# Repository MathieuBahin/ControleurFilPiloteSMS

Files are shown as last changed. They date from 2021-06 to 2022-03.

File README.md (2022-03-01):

# Controleur radiateur avec fil pilote par SMS

Bonjour à tous je vous propose aujourd'hui un projet pour contrôler un radiateur par SMS. Le radiateur doit posséder l'option "Fil pilote".

Mon besoin est de pouvoir piloter la mise en marche d'un radiateur situé dans une résidence secondaire à distance. L'idée est de pouvoir envoyer un ordre à une unité réceptrice qui va allumer le radiateur et me permettre d'arriver 1/2 jours plus tard avec une température correcte dans la résidence.

Des produits similaires existent mais la plupart proposent une communication par Internet, non compatible avec la configuration de la résidence secondaire.

Attention vous allez manipuler des courants mortels je vous conseille une grande vigilance lors des manipulations.

## Electronique

### La communication par fil pilote
On retrouve ci-dessous les commandes pour piloter le radiateur :

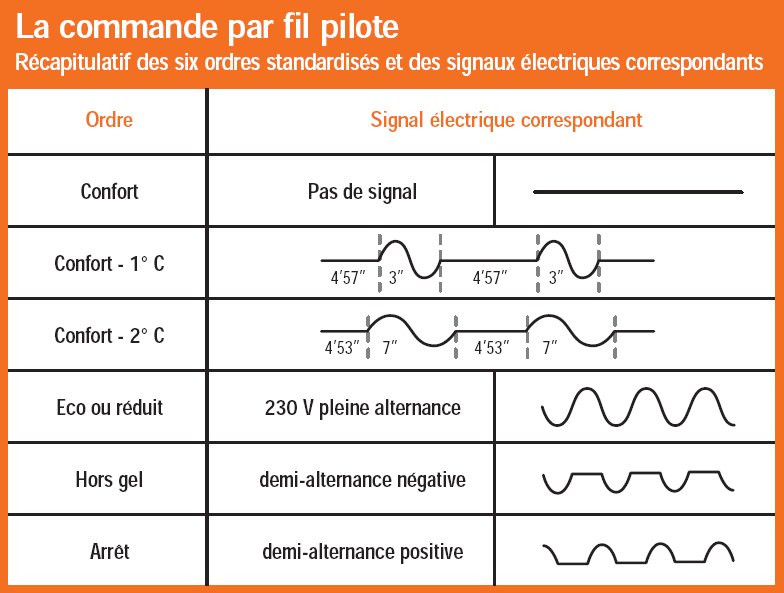
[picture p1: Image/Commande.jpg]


[Source](https://www.planete-domotique.com/blog/2012/01/05/piloter-un-radiateur-grace-a-son-fil-pilote/)

Le radiateur est donc piloté grâce à la sinusoïde 230V.

Pour créer les demi-alternances positives et négatives on utilise les optocoupleurs et les diodes.

En effet une diode dans le sens passant du 230V créer une demi-alternance positive et une diode dans le sens non passant crée une demi-alternance négative. Les optocoupleurs permettent de choisir si le chemin positif, négatif ou les deux sont utilisés.

### Composants utilisés
Pour le projet voici les composants utilisés : 

| Nom |  Coût |
| --- |:-----:|
| Arduino Nano x1 | 2€  |
| [SIM800L](https://www.amazon.fr/Sim800l-Quadribande-Embarqu%C3%A9e-Antenne-Arduino/dp/B01FQPLG9W) x1 | 6€ |
| [DS18B20](https://www.amazon.fr/ANGEEK-capteurs-temp%C3%A9rature-num%C3%A9riques-TO92-55%C2%B0C/dp/B07VB25GS5/) x1 |  8€ pour 5 |
| [IRM-10-5](https://fr.rs-online.com/web/p/alimentations-a-decoupage/1358929/) x1 |  10€ |
| [ZFKDS gauche](https://fr.rs-online.com/web/p/borniers-pour-circuits-imprimes/8045105/)  x1 | 0.50€ |
| [ZFKDS droit](https://fr.rs-online.com/web/p/borniers-pour-circuits-imprimes/8045102/) x1  | 16.70€ pour 50 |
| [MOC3043M](https://fr.rs-online.com/web/p/optocoupleurs/1611159) x2 | 7.76€ pour 10 |
| Résistance 4.7k | |
| Résistance 1.8k | |
| Résistance 1k | |
| Résistance 680 | |
| Diode 1N4007 x3 | |
| Condensateur 470µF [Farnell](https://fr.farnell.com/panasonic-electronic-components/eeufr0j471/condensateur-470-f-6-3v-20/dp/2805615) | |

Le capteur de température et la résistance R9 associée sont optionnels.
Les connecteurs ZFKDS peuvent être remplacés par des borniers etc.
Le condensateur n'est pas optionnel.
Le microcontrôleur Arduino est remplaçable par d'autres (par exemple un PIC8F ou autres) mais le code ne sera pas portable sur les autres plateformes telles quelles.

## Projet KiCad
Les fichiers KiCad sont situés dans le dossier KiCad. Les PCB sont gravés chez [JLCPCB](https://jlcpcb.com/).

Attention pour le module SIM800L a la tension d'alimentation qui est spéciale. J'utilise la tension de chute de la diode pour l'alimenter selon la datasheet. Un pont diviseur est également nécessaire pour la communication UART (5V → 3.3V).

Une fois le PCB reçu je vous conseille de souder le transformateur en dernier.

Si vous souhaitez faire une vérification sur le 230V à la sortie du fil pilote noté que votre multimètre ne vous indiquera pas 115V et si vous souhaitez vérifier avec un oscilloscope faite attention à utiliser une sonde différentielle !

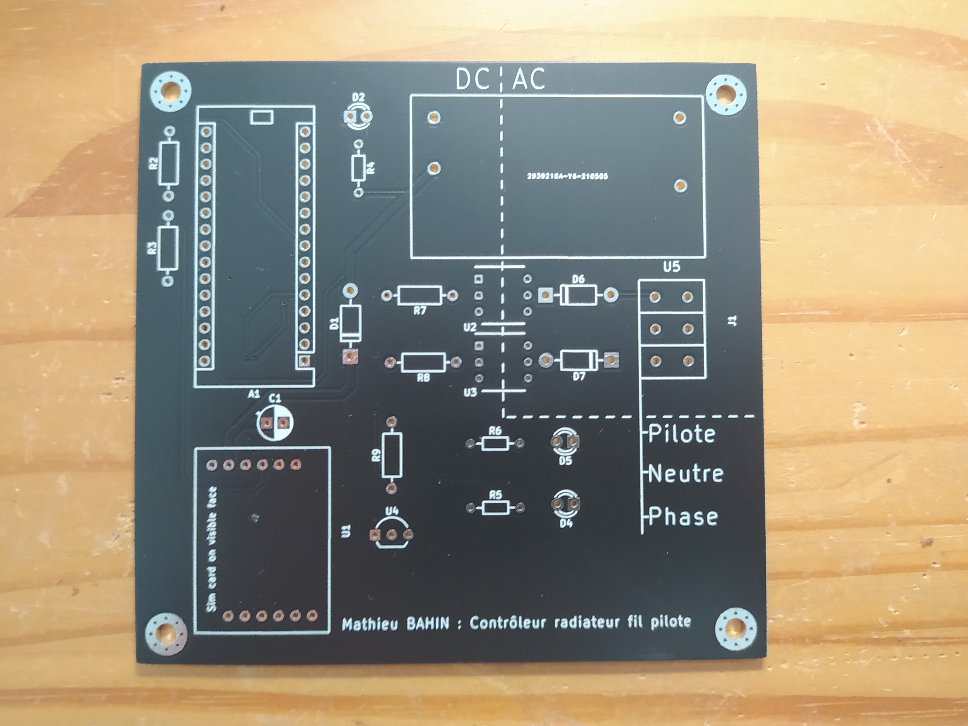
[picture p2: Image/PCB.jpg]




## Développement Arduino
Vous pouvez utiliser l'IDE de votre choix j'utilise personnellement l'IDE Arduino.

Ajoutez les librairies dans votre dossier Arduino (généralement Documents\Arduino\libraries) sinon depuis l'IDE "Croquis → Inclure une bibliothèque"

Dans Outil choisissez votre carte : Arduino Nano et le processeur qui correspond à votre carte.

Puis connectez votre Arduino et flashez le programme.

Vous pouvez ouvrir le moniteur série à 9600 pour voir l'initialisation des composants.

Attention à remplir le numéro de téléphone ou vous souhaitez recevoir les sms. La carte SIM ne doit pas avoir de code PIN.

## Boitier

J'ai choisi un boitier de dérivation de 110x110mm. Vous pouvez soit fixer la carte électronique au fond avec des vis / écrous ou mettre un point de colle dans les coins.

## Installation

N'inversez pas la phase et le neutre, pour différencier les fils (en faisant très attention) munissez-vous de votre multimètre et prenez pour référence la terre.

Phase + terre environ égale à 230V

Neutre + terre environ égale à 0V

Le PCB n'a pas de protection contre les inversions, il est indispensable de brancher la phase sur l'entrée phase sinon le fil pilote ne fonctionnera pas. 

Sectionnez le fil de phase et le fil de neutre (en ayant disjoncté), ajouter un domino de 3 sur la phase et 3 sur le neutre. Branchez le fil pilote du radiateur directement sur la carte. La phase venant du mur va dans le domino qui repart en 2 fils, vers le boitier et vers le radiateur. Idem pour le neutre.



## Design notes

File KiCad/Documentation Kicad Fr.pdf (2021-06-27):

# Documentation modification du projet Kicad

Ouvrir depuis Kicad le projet .pro

## Charger les librairies dans le projet

Modification schéma électrique :
Dans préférences / Configurer les chemins de symboles / Librairies globales :
- Cliquer sur l’icône Dossier puis sélectionner les librairies utilisées ici
- lib_dcm / Ctrl+A Entrer

Modification routage :
Dans préférences / Configurer les Librairies d’empreintes / Librairies globales :
- Cliquer sur l’icône Dossier puis sélectionner les empreintes utilisées ici
- perso .pretty (sélection du dossier)

Si l’application crash ou reste très longtemps en mode « Ne répond pas » :

- Cliquer sur
- Le logiciel charge les empreintes (long) puis préférences / Configurer les Librairies d’empreintes / Librairies globales :
- Cliquer sur l’icône Dossier puis sélectionner les empreintes utilisées ici
- perso .pretty (sélection du dossier)

Si les librairies ne sont pas chargées certains composants apparaissent comme une boite avec des ? à l’intérieur (en mode édition de schéma électronique).

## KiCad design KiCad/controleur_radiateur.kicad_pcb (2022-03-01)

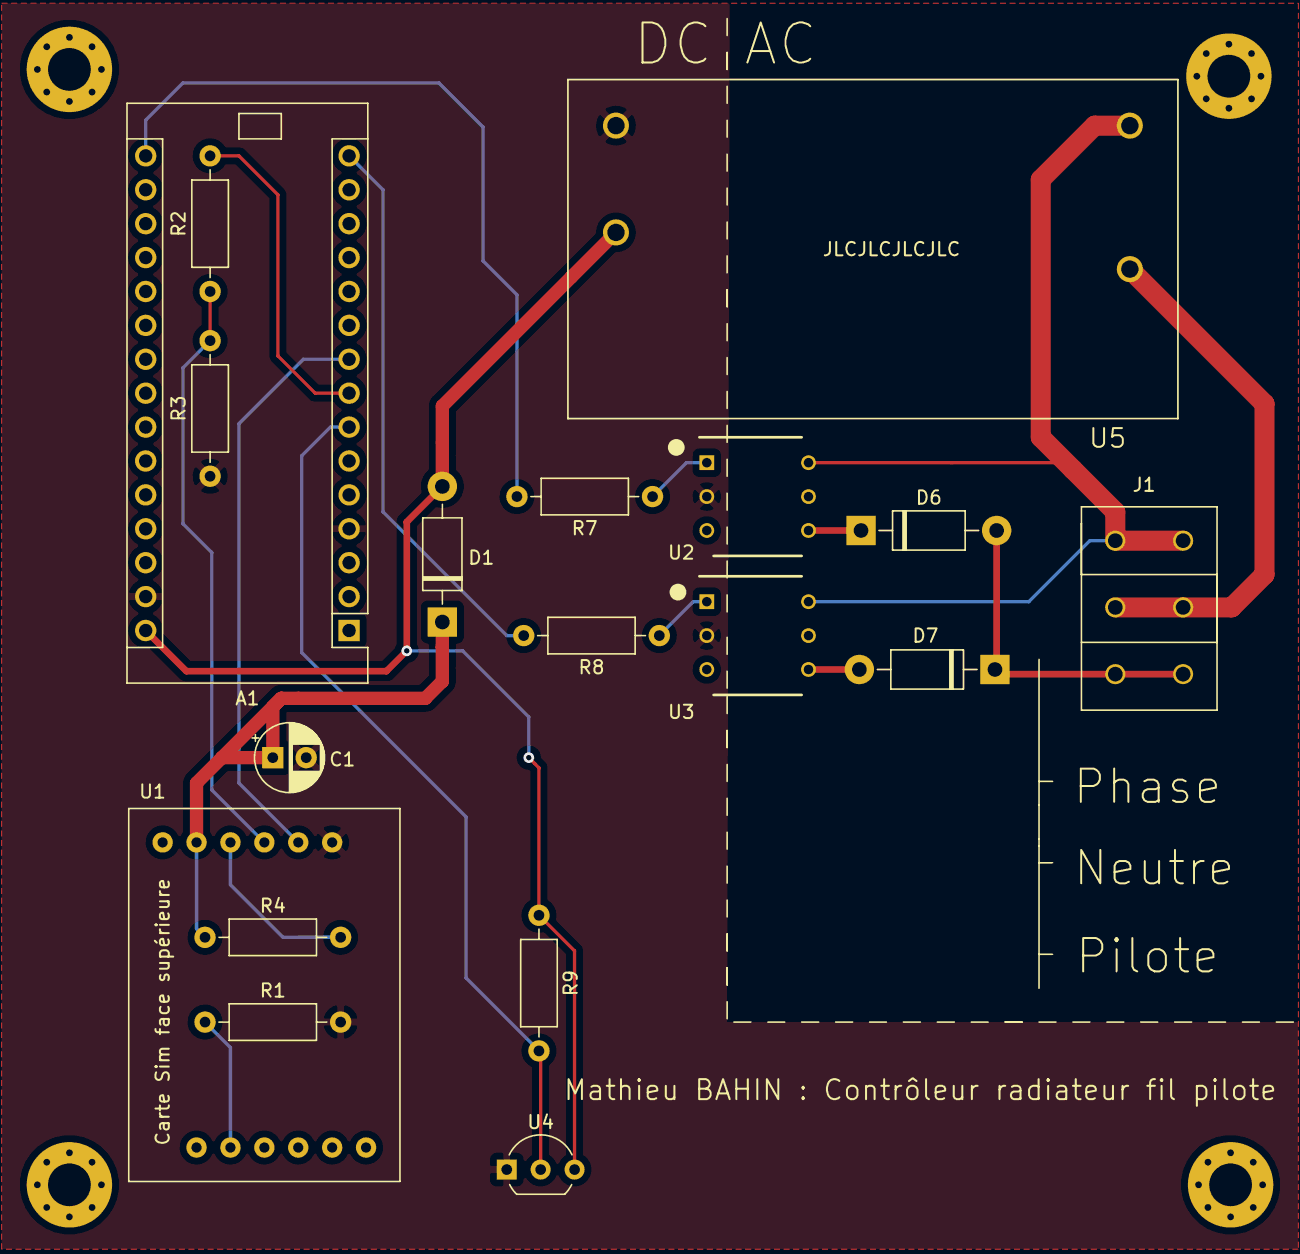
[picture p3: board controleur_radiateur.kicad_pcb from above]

Board: 2 copper layers, 18 parts (0 on the bottom side), 18 nets.

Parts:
A1: Arduino_Nano_v3.x; Arduino_Nano_step
C1: 100u 10V; CP_Radial_D5.0mm_P2.50mm
D1, D6, D7: 1N4007; D_DO-41_SOD81_P10.16mm_Horizontal
J1: ZFKDS_3
R1, R4, R9: 4.7k; R_Axial_DIN0207_L6.3mm_D2.5mm_P10.16mm_Horizontal
R2: 1k; R_Axial_DIN0207_L6.3mm_D2.5mm_P10.16mm_Horizontal
R3: 1.8k; R_Axial_DIN0207_L6.3mm_D2.5mm_P10.16mm_Horizontal
R7, R8: 680; R_Axial_DIN0207_L6.3mm_D2.5mm_P10.16mm_Horizontal
U1: SIM800L; SIM800L_module
U2, U3: MOC3023M
U4: DS18B20; TO-92_Inline_Wide
U5: IRM-10-5

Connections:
+5V: A1.30, D1.2, R9.1, U4.3, U5.4
/D12: A1.15, R8.2
/D13: A1.16, R7.2
/RX_GSM: R2.1, R3.2, U1.4
/TX_GSM: A1.9, U1.5
/Temp_Data: A1.7, R9.2, U4.2
GND: A1.4, A1.29, C1.2, R1.2, R3.1, U1.6, U2.2, U3.2, U4.1, U5.3
unnamed: A1.8, R2.2
unnamed: C1.1, D1.1, R4.1, U1.2
unnamed: D6.1, U2.4
unnamed: D6.2, D7.1, J1.5, J1.6
unnamed: D7.2, U3.4
unnamed: J1.1, J1.2, U2.6, U3.6, U5.2
unnamed: J1.3, J1.4, U5.1
unnamed: R1.1, U1.8
unnamed: R4.2, U1.3
unnamed: R7.1, U2.1
unnamed: R8.1, U3.1

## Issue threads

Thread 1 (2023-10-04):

erreur compilation

kopascal, 2023-10-04:
Bonjour,

Merci pour le partage !!
J'essaie votre code et j'ai une erreur à la compilation :

### C:\Users\Admin\Documents\Arduino\chauffage arduino mathieubahin\ControleurFilPiloteSMS-main\GSM_Controleur_Radiateur\GSM_Controleur_Radiateur.ino: In function 'void check_GSM()':
C:\Users\Admin\Documents\Arduino\chauffage arduino mathieubahin\ControleurFilPiloteSMS-main\GSM_Controleur_Radiateur\GSM_Controleur_Radiateur.ino:298:23: warning: comparison is always true due to limited range of data type [-Wtype-limits]
     if (u8_CREG_Index != -1) // le message reçue est +CREG: x,y

J'ai remplacé par  "unsigned char" par "char" dans void check_GSM(), pas d'erreur, mais cela a-t-il une incidence ?

J'ai commandé des CI que j'attends pour tester.

Bien cordialement
Pascal Kolly

void check_GSM()
{
    String str_recep;
    // unsigned char u8_CREG_Index = 0; **remplacée par celle dessous pour éviter erreur compil**
    char u8_CREG_Index = 0;
    #ifdef DEBUG
        Serial.println("Vérification GSM connecté");
    #endif
    Serial_Sim.println("AT+CREG?");
    delay(1000);

    while (Serial_Sim.available())
  	{
        st_gsm.s8_received = Serial_Sim.read();  // 1 caractère
		str_recep.concat(st_gsm.s8_received);	//on concatène le char à la chaine
        delay(1); // nécessaire car la liaison uart est 9600 (1ms par caractère)
        #ifdef DEBUG
            Serial.print(st_gsm.s8_received);
        #endif

MathieuBahin, 2023-10-09:
Bonjour,
non pas d'incidence. Cette variable est utilisé pour récupérer l'index du caractère virgule. Il est effectivement possible que l'index soit négatif si le caractère n'est pas trouvé.
Si vous le souhaitez vous pouvez faire une pull request qui corrige le problème.
N'hésiter pas à me tenir au courant de vos avancées. Pour info le prototype tourne non stop depuis maintenant 2 ans sans problème (mis à part que les utilisateurs s'attendent à recevoir la réponse instantanément même si le réseau n'est pas bon)
Slt
Mathieu

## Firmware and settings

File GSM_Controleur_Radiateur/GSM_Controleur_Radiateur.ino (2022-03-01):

#define DEBUG
#define Pin_MOC_Haut 13     // D13  
#define Pin_MOC_Bas 12      // D12 
#define Pin_Temperature 4   // D4

#include "OneWire.h"	    // capteur température
#include "SoftwareSerial.h"	// SIM800L
#include <EEPROM.h>         // EEPROM sauvegarde mode pilote
#include <avr/wdt.h >	    // watchdog pour reset

#define CONFORT 1   // mode sauvegarde en EE
#define ECO 2       // mode sauvegarde en EE
#define HORS_GEL 3  // mode sauvegarde en EE
#define ARRET 4     // mode sauvegarde en EE

#define GSM_CHECK_INTERVAL 60000    // 60s test connection GSM

#define set_Confort() set_Pilote(0, 0)
#define set_Eco()     set_Pilote(1, 1)
#define set_HorsGel() set_Pilote(1, 0)
#define set_Arret()   set_Pilote(0, 1)

SoftwareSerial Serial_Sim(6, 5);	// pin6 =  D6 = RX, pin5 =  D5 = TX  Arduino Nano
OneWire Temperature(Pin_Temperature);
unsigned char u8_EE_addr = 0;	    // adresse EEPROM u8_mode_pilote du fil pilote  
unsigned long u32_tempsPrecedent = 0;

// structure contenant les infos liées au capteur de température  
struct st_Data_Temp
{
	byte u8_type_capteur;
	byte u8_data[12];
	byte u8_addr[8];
	byte u8_present;
	float f_celsius;
};
st_Data_Temp st_temperature;

// structure contenant les infos liées au module SIM800L  
struct st_Data_Sim
{
	char s8_received;	           // caractère reçu
	String str_gsm_data;	       // concaténation des caractères reçus
	String str_numero_tel;	       // numéro de téléphone (figé pour le moment)
	unsigned char u8_mode_pilote;  // u8_mode_pilote du fil pilote (confort, etc)
};
st_Data_Sim st_gsm;


void setup()
{
	pinMode(Pin_MOC_Haut, OUTPUT);	            // MOC haut 
	pinMode(Pin_MOC_Bas, OUTPUT);	            // MOC bas
    set_Arret();                                // valeur initial (sinon démarre sur confort)
	st_gsm.str_numero_tel = "+33xxxxxxxxx";	    // numéro de téléphone 
    #ifdef DEBUG
        Serial.begin(9600);
        Serial.println("Démarrage programme");
    #endif
	Serial_Sim.begin(9600);
    
    delay(5000);                                // laisse le module démarrer
	Serial_Sim.println("AT");	                // répond OK 
	updateSerial();
    delay(1000);
    Serial_Sim.println("AT+CFUN=0");	        // configure mode avion ON
	updateSerial();
    delay(3000);
    Serial_Sim.println("AT+CFUN=1");	        // configure mode avion OFF
	updateSerial();
    delay(3000);
	Serial_Sim.println("AT+CMGF=1");	        // configure mode TEXT
	updateSerial();
    delay(1000);
	Serial_Sim.println("AT+CNMI=1,2,0,0,0");	// paramètrage réception sms
	updateSerial();
    delay(1000);
    
    #ifdef DEBUG
        Serial_Sim.println("AT+COPS?");         // liste les réseaux disponibles 
        updateSerial();
        delay(1000);
        Serial.println("GSM OK");
    #endif
    
	updateSerial();

	if (!Temperature.search(st_temperature.u8_addr))
	{
        #ifdef DEBUG
            Serial.println("Plus d'adresses.");
            Serial.println();
        #endif
		Temperature.reset_search();
		delay(250);
		return;
	}

	if (OneWire::crc8(st_temperature.u8_addr, 7) != st_temperature.u8_addr[7])
	{
        #ifdef DEBUG
            Serial.println("CRC invalide!");
        #endif
		return;
	}

    #ifdef DEBUG
        Serial.println();
    #endif

	// octet 1 : version du composant 
	switch (st_temperature.u8_addr[0])
	{
		case 0x10: // DS18S20 or old DS1820
			st_temperature.u8_type_capteur = 1;
			break;
		case 0x28: // DS18B20
			st_temperature.u8_type_capteur = 0;
			break;
		case 0x22: // DS1822
			st_temperature.u8_type_capteur = 0;
			break;
		default:
            #ifdef DEBUG
                Serial.println("Composant non reconnu : pas un DS18x20.");
            #endif
			return;
	}

	Temperature.reset();
	Temperature.select(st_temperature.u8_addr);
	Temperature.write(0x44, 1);	// début conversion, parasite power on 
	delay(1000);
	st_temperature.u8_present = Temperature.reset();
    #ifdef DEBUG
        Serial.println("Temperature OK"); 
    #endif

	st_gsm.u8_mode_pilote = EEPROM.read(u8_EE_addr);	// recharge le mode du fil pilote depuis l'eeprom
    switch(st_gsm.u8_mode_pilote)
    {
        case CONFORT:
            set_Confort();
            break;
        case ECO:
            set_Eco();
            break;
        case ARRET:
            set_Arret();
            break;
        case HORS_GEL:
        default:
            set_HorsGel();
            break;
    }
    #ifdef DEBUG
        Serial.println("Initialisation terminée");
    #endif
	updateSerial();
}

/*
 * positionne les 2 sorties qui controlent les optocoupleurs
 */
void set_Pilote(char h, char l)
{
	digitalWrite(Pin_MOC_Haut, h);
	digitalWrite(Pin_MOC_Bas, l);
}

/*
 * acquisition et ecriture de la température dans la variable situé dans la structure
 */
void read_Celsius()
{
	unsigned char i = 0;
	Temperature.reset();
	Temperature.select(st_temperature.u8_addr);
	Temperature.write(0x44, 1);	// début conversion, parasite power on 
	delay(1000);

	st_temperature.u8_present = Temperature.reset();
	Temperature.select(st_temperature.u8_addr);
	Temperature.write(0xBE);	// lire Scratchpad

    #ifdef DEBUG
        Serial.print("  u8_data = ");
        Serial.print(st_temperature.u8_present, HEX);
        Serial.print(" ");
    #endif
	for (i = 0; i < 9; i++) // 9 octets
	{
		st_temperature.u8_data[i] = Temperature.read();
        #ifdef DEBUG
            Serial.print(st_temperature.u8_data[i], HEX);
            Serial.print(" ");
        #endif
	}
    #ifdef DEBUG
        Serial.print(" CRC=");
        Serial.print(OneWire::crc8(st_temperature.u8_data, 8), HEX);
        Serial.println();
    #endif

	// Convertir les données en température
	// résultat 16 bits signées
	int16_t raw = (st_temperature.u8_data[1] << 8) | st_temperature.u8_data[0];
	if (st_temperature.u8_type_capteur)
	{
		raw = raw << 3;	// resolution 9 bits par défault
		if (st_temperature.u8_data[7] == 0x10)
		{
			// "count remain" résolution 12 bit 
			raw = (raw & 0xFFF0) + 12 - st_temperature.u8_data[6];
		}
	}
	else
	{
		byte cfg = (st_temperature.u8_data[4] &0x60);
		// en résolution basse les lsd sont non définie donc on les mets à zéro
		if (cfg == 0x00) raw = raw &~7;	// 9 bits, 93.75 ms
		else if (cfg == 0x20) raw = raw &~3;	// 10 bits, 187.5 ms
		else if (cfg == 0x40) raw = raw &~1;	// 11 bits, 375 ms
		// defaut resolution 12 bit, 750 ms 
	}

	st_temperature.f_celsius = (float) raw / 16.0;
    #ifdef DEBUG
        Serial.print("  Temperature = ");
        Serial.print(st_temperature.f_celsius);
        Serial.print(" f_celsius, ");
        Serial.println("");
    #endif
}

/*
 * SIM800L mode réception
 */
void ReceiveMode()
{
	Serial_Sim.println("AT");	//répond "OK"
	updateSerial();
	Serial_Sim.println("AT+CMGF=1");	// Configurer mode TEXT 
	updateSerial();
	Serial_Sim.println("AT+CNMI=2,2,0,0,0");	// paramètrage réception sms
	updateSerial();
}

/*
 * Envoie la chaine situé dans st_gsm.str_gsm_data au numéro st_gsm.str_numero_tel
 */
void Send_Data()
{
    #ifdef DEBUG
        Serial.println("Envoie des données sms ...");
    #endif
	Serial_Sim.print("AT+CMGF=1\r");	// mode SMS
	delay(100);
	Serial_Sim.print("AT+CMGS=\"" + st_gsm.str_numero_tel + "\"\r");
	delay(500);
	Serial_Sim.print(st_gsm.str_gsm_data);	// envoie le contenu de la variable 
	delay(500);
	Serial_Sim.print((char) 26);	// requis pour confirmer l'envoie
	delay(500);
	Serial_Sim.println();
    #ifdef DEBUG
        Serial.println("Données envoyés.");
    #endif
	delay(500);

}

/*
 * Vérifie si le GSM est actif, sinon on reset le µC pour relancer la recherche de connection
 */
void check_GSM()
{
    String str_recep;
    unsigned char u8_CREG_Index = 0;
    #ifdef DEBUG
        Serial.println("Vérification GSM connecté");
    #endif
    Serial_Sim.println("AT+CREG?");
    delay(1000);

    while (Serial_Sim.available())
  	{
        st_gsm.s8_received = Serial_Sim.read();  // 1 caractère
		str_recep.concat(st_gsm.s8_received);	//on concatène le char à la chaine  
        delay(1); // nécessaire car la liaison uart est 9600 (1ms par caractère)
        #ifdef DEBUG
            Serial.print(st_gsm.s8_received);
        #endif
	}
    
    u8_CREG_Index = str_recep.indexOf(",");
    if (u8_CREG_Index != -1)	// le message reçue est +CREG: x,y
	{
        switch(str_recep.charAt(u8_CREG_Index + 1)) // https://docs.eseye.com/Content/ELS61/ATCommands/ELS61CREG.htm
        {
            /* ok on peut recevoir des SMS */
            case '1' : // Registered to home network.
            case '2' : // Not registered, but the device is currently searching for a new operator. 
            case '5' : // Registered, roaming. The device is registered on a foreign (national or international) network.
                
                break;
                
            /* pas ok on reset le µC */    
            case '0' : // Not registered, the device is currently not searching for new operator.
            case '3' : // Registration denied.
            case '4' : // Unknown. For example, out of range.
            default :
                wdt_enable(WDTO_15MS); // on reset 
				while (1) {}
                #ifdef DEBUG
                    Serial.println("Jamais atteint");
                #endif
                break;
        }
	}
}

/*
 * Réception des données, transfère entre GSM et terminal série
 */
void updateSerial()
{
    #ifdef DEBUG
        while (Serial.available())
        {
            Serial_Sim.write(Serial.read());	// Renvoie ce qui est lu sur la liaison série GSM vers la console
        }
  
        while (Serial_Sim.available())
        {
            Serial.write(Serial_Sim.read());	// Renvoie ce qui est lu sur la liaison série PC vers le GSM (non utilisé)
        }
    #else
        while (Serial_Sim.available())
        {
            Serial_Sim.read();                  // Lire sinon boucle de sms envoyé
        }
    #endif
}

void loop()
{
	String str_rx;	// concaténation des caractères lus par la liaison série
    unsigned long u32_tempsCourant = millis(); // actualise temps
    if(u32_tempsCourant - u32_tempsPrecedent >= GSM_CHECK_INTERVAL) // vérification connection
    {
        u32_tempsPrecedent = u32_tempsCourant;
        check_GSM(); 
    }
    
	while (Serial_Sim.available() > 0)
	{
		st_gsm.s8_received = Serial_Sim.read();	// 1 caractère
        #ifdef DEBUG
            Serial.print(st_gsm.s8_received);
        #endif
		str_rx.concat(st_gsm.s8_received);	// on concatène le char au string
		if (str_rx.indexOf("Temp") != -1)	// le message contient Temp -> on renvoie la température
		{
			read_Celsius();
			st_gsm.str_gsm_data = "Temperature : " + String(st_temperature.f_celsius) + " C";
			Send_Data();
			ReceiveMode();
		}
		else
		{
			if (str_rx.indexOf("Confort") != -1)	// on positionne les optocoupleurs et en renvoie ok
			{
				set_Confort();
				st_gsm.u8_mode_pilote = CONFORT;
				EEPROM.write(u8_EE_addr, st_gsm.u8_mode_pilote);
				st_gsm.str_gsm_data = "OK Confort";
				Send_Data();
				ReceiveMode();
			}
			else
			{
				if (str_rx.indexOf("Arret") != -1)	// on positionne les optocoupleurs et en renvoie ok
				{
					set_Arret();
					st_gsm.u8_mode_pilote = ARRET;
					EEPROM.write(u8_EE_addr, st_gsm.u8_mode_pilote);
					st_gsm.str_gsm_data = "OK Arret";
					Send_Data();
					ReceiveMode();
				}
				else
				{
					if (str_rx.indexOf("Eco") != -1)	// on positionne les optocoupleurs et en renvoie ok
					{
						set_Eco();
						st_gsm.u8_mode_pilote = ECO;
						EEPROM.write(u8_EE_addr, st_gsm.u8_mode_pilote);
						st_gsm.str_gsm_data = "OK Eco";
						Send_Data();
						ReceiveMode();
					}
					else
					{
						if (str_rx.indexOf("Hors") != -1)	// on positionne les optocoupleurs et en renvoie ok
						{
							set_HorsGel();
							st_gsm.u8_mode_pilote = HORS_GEL;
							EEPROM.write(u8_EE_addr, st_gsm.u8_mode_pilote);
							st_gsm.str_gsm_data = "OK Hors gel";
							Send_Data();
							ReceiveMode();
						}
						else
						{
							if (str_rx.indexOf("Mode") != -1)	// on répond à la requete et on envoie le mode actuel
							{
								switch (st_gsm.u8_mode_pilote)
								{
									case ARRET:
										st_gsm.str_gsm_data = "Mode arret";
										break;
									case CONFORT:
										st_gsm.str_gsm_data = "Mode confort";
										break;
									case ECO:
										st_gsm.str_gsm_data = "Mode eco";
										break;
									case HORS_GEL:
										st_gsm.str_gsm_data = "Mode hors gel";
										break;
								}
								Send_Data();
								ReceiveMode();
							}
							else
							{
								if (str_rx.indexOf("Reset") != -1)	// on force le reset de l'arduino
								{
									wdt_enable(WDTO_15MS);
									while (1) {}
                                        #ifdef DEBUG
                                            Serial.println("Jamais atteint");
                                        #endif
								}
								else
								{
									// pas reconnu on ne fait rien !!!  (si tel surtaxé envoie sms)
								}
							}
						}
					}
				}
			}
		}
	}
}

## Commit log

2021-06-23 Ajout des explications dans le Readme
2021-06-27 [ADD] fichier KiCad
    [controleur_radiateur-B_Cu.gbr, controleur_radiateur-B_Mask.gbr, controleur_radiateur-B_Paste.gbr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]
2021-06-27 Pas de communication SMS pour le moment A FAIRE
2021-06-27 [MAJ] modification pour les libs
    [controleur_radiateur.kicad_pcb, controleur_radiateur.sch]
2021-06-27 [+] librairie kicad
2021-09-28 Communication, rechargement depuis EEPROM, mode pilote
    vérifier les define des set_Pilote
2021-09-28 Changement suite à l'ajout du code Arduino
2021-09-28 code PIN de la SIM désactiver
2022-03-01 PCB : suppression des led, changement optocoupleurs pour des MOC3043M, redesign du PCB Soft : reconnection automatique toutes les 1 minutes au réseau GSM
    [controleur_radiateur-B_Cu.gbr, controleur_radiateur-B_Mask.gbr, controleur_radiateur-B_Paste.gbr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]
